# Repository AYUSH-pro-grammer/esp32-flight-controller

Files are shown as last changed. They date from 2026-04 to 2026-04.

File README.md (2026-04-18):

# ESP32 Flight Controller (Custom PCB)

## Description

This project presents a basic custom flight controller that is based on the ESP32 and MPU6050 IMU chip. The project reads data from the sensors, uses PID control to stabilize the drone, and drives four motors through electronic speed controllers (ESC).

## How PCB will look
PCB Image

## kicad schematic

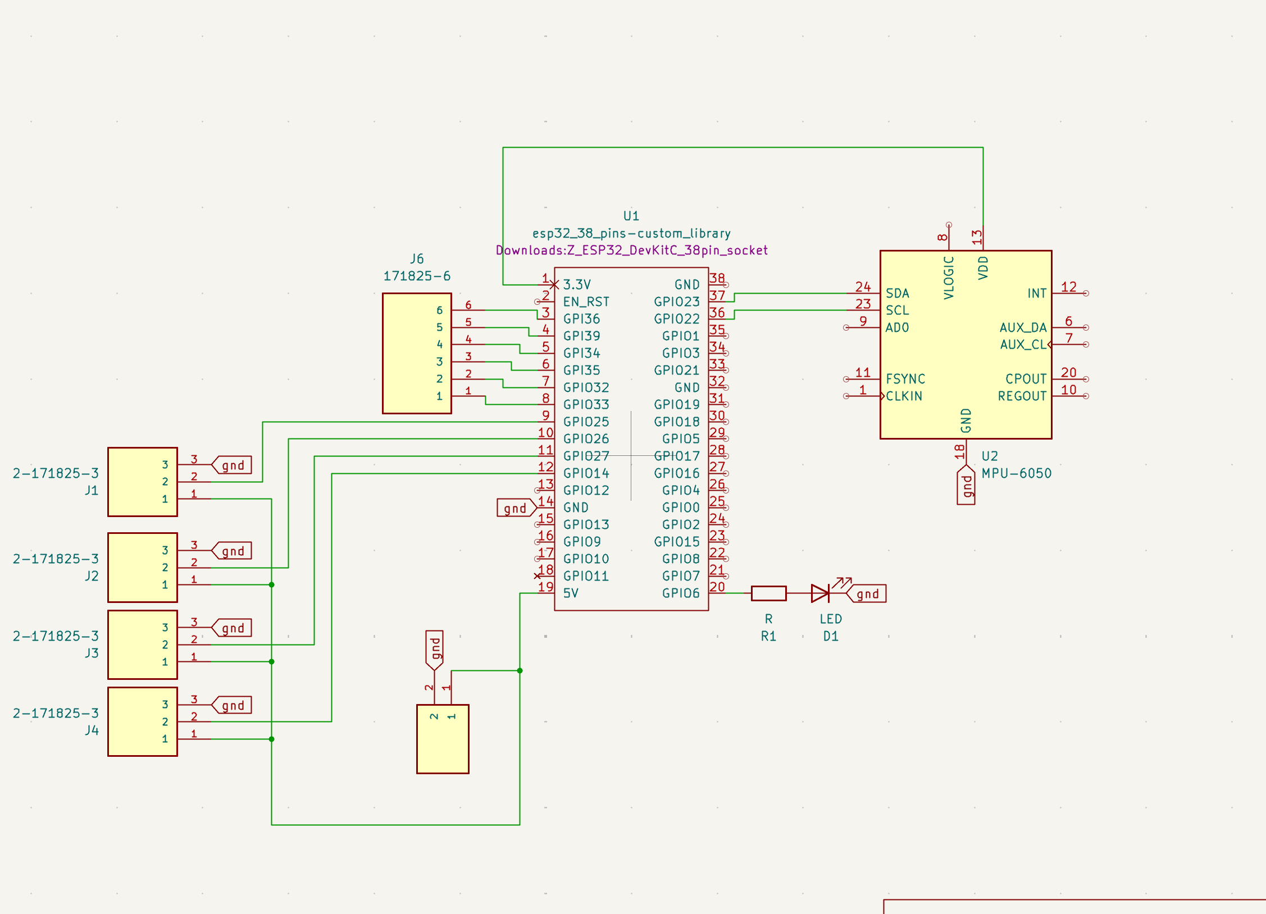
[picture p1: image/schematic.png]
Schematic


The repository contains:

* Code for the flight controller
* Code for IMU calibration
* Files with PCB design (KiCad)
* Gerber files for board manufacture

---

## Project Directory Structure

```
flight-controller-code/
├── flightController.ino   # Flight controller code
├── calibration.ino        # IMU calibration code
├── kicad/                 # PCB design files
├── image/                 # Board images
├── main_grb.zip           # Gerber files for fabrication
└── README.md
```

---

## Features

* Integration of MPU6050 accelerometer and gyroscope
* Complementary filter algorithm for angle calculations
* Double-loop PID control (angle and angle rate)
* PWM signals to control 4 ESC motors
* Input from the RC receiver (6 channels)
* IMU calibration for accurate sensor offset values

---

## Hardware Requirements

* ESP32 microcontroller
* MPU6050 IMU
* 4 electronic speed controllers with brushless motors
* RC receiver (PWM protocol)
* LiPo battery
* Custom PCB (designed in KiCad, files in `kicad/` folder)

---

## Setup Procedure

### Step 1 - Upload Calibration Code

1. Load file `calibration.ino`
2. Program ESP32 with this code
3. Put the drone on the ground
4. Open the Serial Monitor window
5. Read instruction messages and save the output values

---

### Step 2 - Fill IMU Offset Values

Fill the calibration values into the file `flightController.ino`:

```
float rateRollOffset = ...;
float ratePitchOffset = ...;
float rateYawOffset = ...;

float accXOffset = ...;
float accYOffset = ...;
float accZOffset = ...;
```

---

### Step 3 - Upload the Main Code

* Load `flightController.ino`
* Program ESP30 with this code

---

## Controls (RC Mapping)

| Channel | Function  |
| --- | --- |
| CH1 | Roll |
| CH2 | Pitch |
| CH3 | Throttle  |
| CH4 | Yaw |
| CH5/CH6 | Auxiliary |

---

## Important Tips

* Make sure your motors are installed correctly
* Do not run any tests with propellers mounted
* Fine-tune PID coefficients for better stability
* Calibrate your sensors carefully for optimal results

---

## Safety

* Do not power the motors with mounted propellers
* Ensure reliable power supply
* Have your hand near the throttle button

---

## Possible Upgrades

* Build-in fail-safe system
* Implement altitude hold function
* Enable GPS functionality
* Improve filtering algorithm (Kalman filter)

---

## Reference Code

Key code fragments are found in the following file:

---

## License

This project is open-source and can be freely modified.

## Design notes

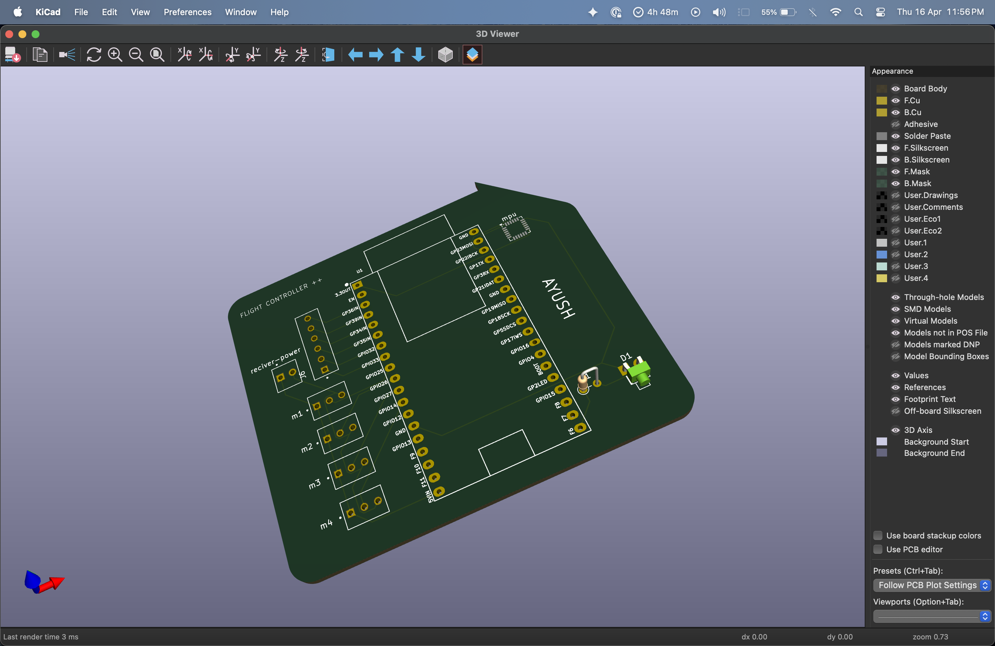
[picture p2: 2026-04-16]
image/3d.png

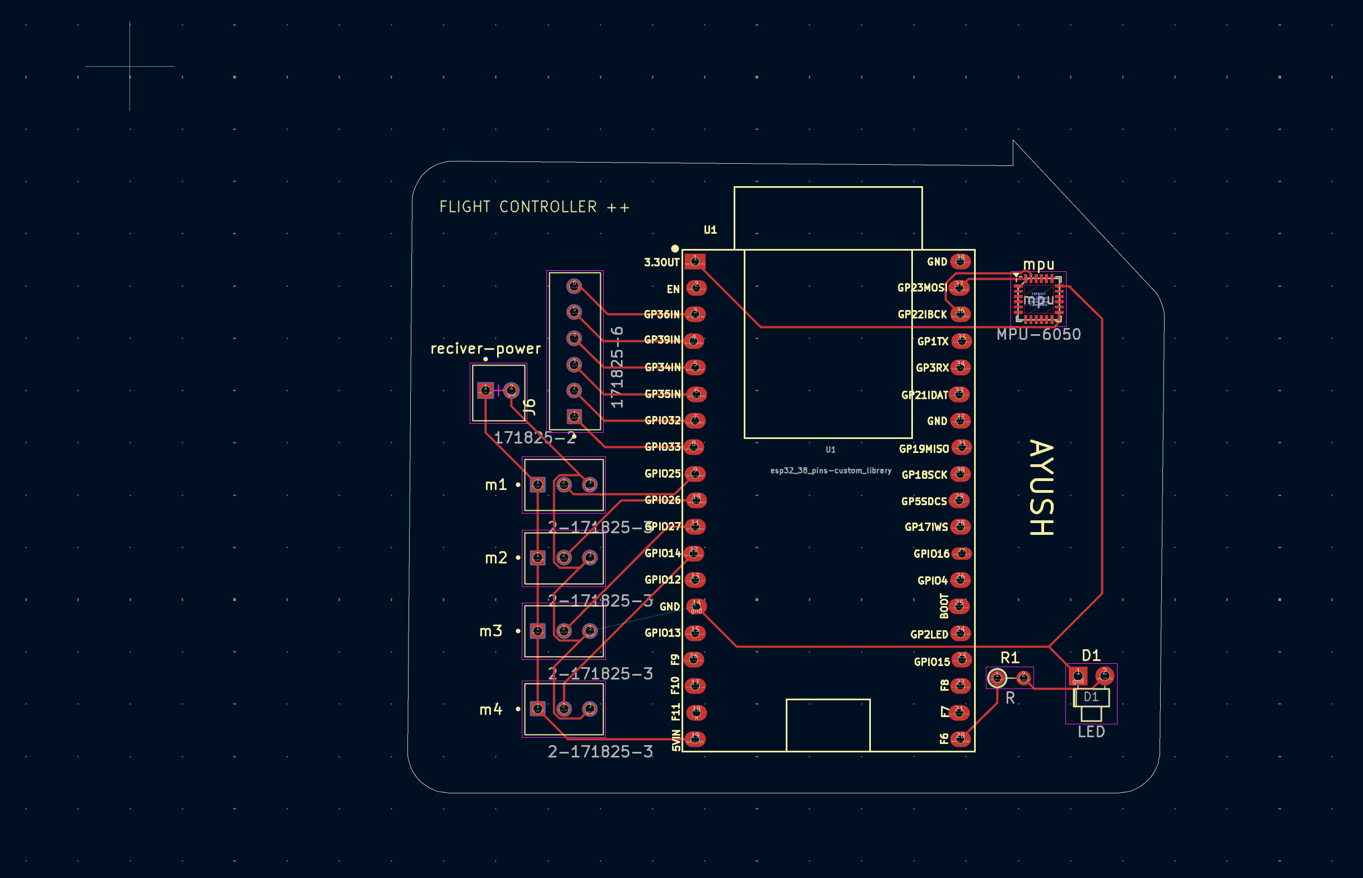
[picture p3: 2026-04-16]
image/pcb-editer.png

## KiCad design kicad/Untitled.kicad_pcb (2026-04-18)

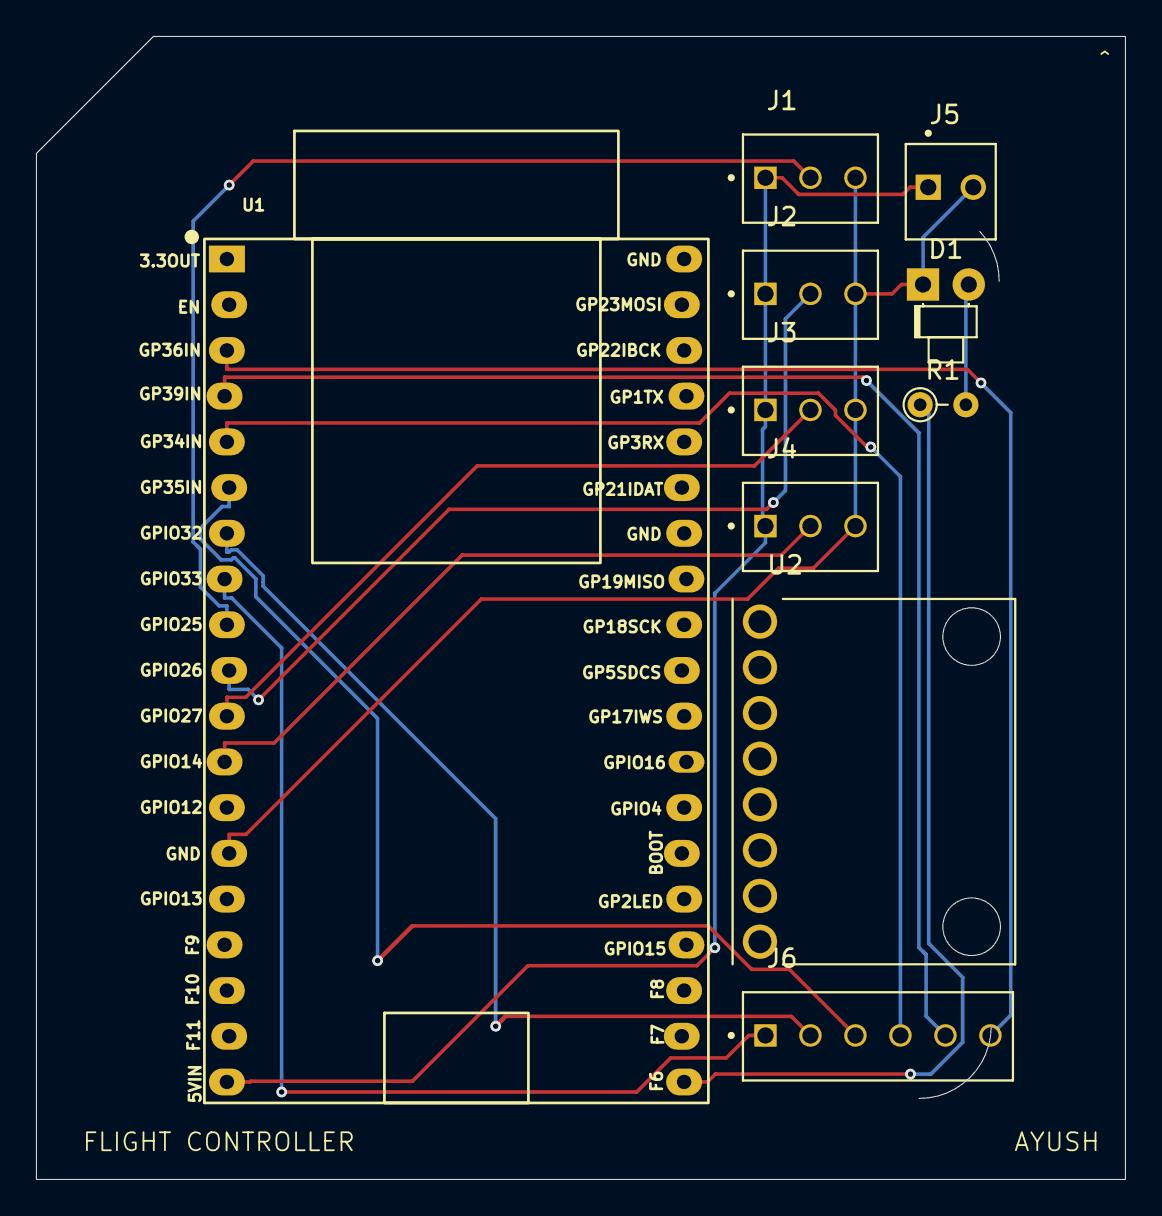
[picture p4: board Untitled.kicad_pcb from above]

Board: 2 copper layers, 60.5 x 63.5 mm, 10 parts (0 on the bottom side), 14 nets.

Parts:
D1: LED; LED_D1.8mm_W1.8mm_H2.4mm_Horizontal_O1.27mm_Z1.6mm
J1, J2, J3, J4: 2-171825-3; TE_2-171825-3
J5: 171825-2; TE_171825-2
J6: 171825-6; TE_171825-6
R1: R; R_Axial_DIN0204_L3.6mm_D1.6mm_P2.54mm_Vertical
U1: esp32_38_pins-custom_library; Z_ESP32_DevKitC_38pin_socket
U2: MPU-6050; MODULE_GY-521

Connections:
unnamed: D1.2 (A), R1.2
unnamed: J1.1, J2.1, J3.1, J4.1, J5.1, U1.19 (5V)
unnamed: J6.4, U1.5 (GPI34)
unnamed: J6.3, U1.6 (GPI35)
unnamed: J6.6, U1.3 (GPI36)
unnamed: J6.5, U1.4 (GPI39)
unnamed: R1.1, U1.20 (GPIO6)
unnamed: J4.2, U1.12 (GPIO14)
unnamed: J1.2, U1.9 (GPIO25)
unnamed: J2.2, U1.10 (GPIO26)
unnamed: J3.2, U1.11 (GPIO27)
unnamed: J6.2, U1.7 (GPIO32)
unnamed: J6.1, U1.8 (GPIO33)
gnd: D1.1 (K), J1.3, J2.3, J3.3, J4.3, J5.2, U1.14 (GND)

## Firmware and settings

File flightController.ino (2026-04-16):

#include <Wire.h>
#include <ESP32Servo.h>

const uint8_t MPU_ADDR = 0x68;
const float RAD_TO_DEG = 57.2957795f;
const float dt = 0.004f;

// IMU raw and converted values
int16_t accXRaw, accYRaw, accZRaw;
int16_t gyroXRaw, gyroYRaw, gyroZRaw;

float accX = 0.0f, accY = 0.0f, accZ = 0.0f;
float rateRoll = 0.0f, ratePitch = 0.0f, rateYaw = 0.0f;

// paste calibration values here
float rateRollOffset = 0.0f;
float ratePitchOffset = 0.0f;
float rateYawOffset = 0.0f;
float accXOffset = 0.0f;
float accYOffset = 0.0f;
float accZOffset = 0.0f;

float angleRoll = 0.0f;
float anglePitch = 0.0f;
float compAngleRoll = 0.0f;
float compAnglePitch = 0.0f;

// motors
Servo motor1, motor2, motor3, motor4;

const int motor1Pin = 13;
const int motor2Pin = 12;
const int motor3Pin = 14;
const int motor4Pin = 27;

const int escFrequency = 500;
const int throttleIdle = 1170;
const int throttleCutoff = 1000;

float motor1Out = 1000.0f;
float motor2Out = 1000.0f;
float motor3Out = 1000.0f;
float motor4Out = 1000.0f;

// receiver
volatile int receiverValue[6] = {1500, 1500, 1000, 1500, 1500, 1500};

const int ch1Pin = 34;
const int ch2Pin = 35;
const int ch3Pin = 32;
const int ch4Pin = 33;
const int ch5Pin = 25;
const int ch6Pin = 26;

volatile uint32_t currentTime = 0;
volatile uint32_t lastRise1 = 0, lastRise2 = 0, lastRise3 = 0, lastRise4 = 0, lastRise5 = 0, lastRise6 = 0;
volatile bool lastState1 = false, lastState2 = false, lastState3 = false, lastState4 = false, lastState5 = false, lastState6 = false;

// pid gains
float kpAngleRoll = 2.0f;
float kiAngleRoll = 0.5f;
float kdAngleRoll = 0.007f;

float kpAnglePitch = 2.0f;
float kiAnglePitch = 0.5f;
float kdAnglePitch = 0.007f;

float kpRateRoll = 0.625f;
float kiRateRoll = 2.1f;
float kdRateRoll = 0.0088f;

float kpRatePitch = 0.625f;
float kiRatePitch = 2.1f;
float kdRatePitch = 0.0088f;

float kpRateYaw = 4.0f;
float kiRateYaw = 3.0f;
float kdRateYaw = 0.0f;

// pid state
float desiredAngleRoll = 0.0f;
float desiredAnglePitch = 0.0f;
float desiredRateYaw = 0.0f;

float desiredRateRoll = 0.0f;
float desiredRatePitch = 0.0f;

float errorAngleRoll = 0.0f;
float errorAnglePitch = 0.0f;
float prevErrorAngleRoll = 0.0f;
float prevErrorAnglePitch = 0.0f;
float iTermAngleRoll = 0.0f;
float iTermAnglePitch = 0.0f;

float errorRateRoll = 0.0f;
float errorRatePitch = 0.0f;
float errorRateYaw = 0.0f;
float prevErrorRateRoll = 0.0f;
float prevErrorRatePitch = 0.0f;
float prevErrorRateYaw = 0.0f;
float iTermRateRoll = 0.0f;
float iTermRatePitch = 0.0f;
float iTermRateYaw = 0.0f;

float outRoll = 0.0f;
float outPitch = 0.0f;
float outYaw = 0.0f;

uint32_t loopTimer = 0;

float clampf(float value, float low, float high) {
  if (value < low) return low;
  if (value > high) return high;
  return value;
}

float pidStep(float error, float kp, float ki, float kd, float &integral, float &prevError) {
  integral += ki * error * dt;
  integral = clampf(integral, -400.0f, 400.0f);

  float derivative = kd * (error - prevError) / dt;
  float output = kp * error + integral + derivative;

  prevError = error;
  return clampf(output, -400.0f, 400.0f);
}

void setupMPU() {
  Wire.beginTransmission(MPU_ADDR);
  Wire.write(0x6B);
  Wire.write(0x00);
  Wire.endTransmission();

  Wire.beginTransmission(MPU_ADDR);
  Wire.write(0x1A);
  Wire.write(0x05);
  Wire.endTransmission();

  Wire.beginTransmission(MPU_ADDR);
  Wire.write(0x1C);
  Wire.write(0x10);
  Wire.endTransmission();

  Wire.beginTransmission(MPU_ADDR);
  Wire.write(0x1B);
  Wire.write(0x08);
  Wire.endTransmission();
}

void readMPU() {
  Wire.beginTransmission(MPU_ADDR);
  Wire.write(0x3B);
  Wire.endTransmission();

  if (Wire.requestFrom(MPU_ADDR, (uint8_t)6) != 6) return;

  accXRaw = (Wire.read() << 8) | Wire.read();
  accYRaw = (Wire.read() << 8) | Wire.read();
  accZRaw = (Wire.read() << 8) | Wire.read();

  Wire.beginTransmission(MPU_ADDR);
  Wire.write(0x43);
  Wire.endTransmission();

  if (Wire.requestFrom(MPU_ADDR, (uint8_t)6) != 6) return;

  gyroXRaw = (Wire.read() << 8) | Wire.read();
  gyroYRaw = (Wire.read() << 8) | Wire.read();
  gyroZRaw = (Wire.read() << 8) | Wire.read();

  accX = (float)accXRaw / 4096.0f;
  accY = (float)accYRaw / 4096.0f;
  accZ = (float)accZRaw / 4096.0f;

  rateRoll = (float)gyroXRaw / 65.5f;
  ratePitch = (float)gyroYRaw / 65.5f;
  rateYaw = (float)gyroZRaw / 65.5f;

  rateRoll -= rateRollOffset;
  ratePitch -= ratePitchOffset;
  rateYaw -= rateYawOffset;

  accX -= accXOffset;
  accY -= accYOffset;
  accZ -= accZOffset;

  angleRoll = atan2f(accY, sqrtf(accX * accX + accZ * accZ)) * RAD_TO_DEG;
  anglePitch = -atan2f(accX, sqrtf(accY * accY + accZ * accZ)) * RAD_TO_DEG;
}

void IRAM_ATTR readReceiver() {
  currentTime = micros();

  bool s1 = digitalRead(ch1Pin);
  if (s1 && !lastState1) {
    lastState1 = true;
    lastRise1 = currentTime;
  } else if (!s1 && lastState1) {
    lastState1 = false;
    receiverValue[0] = currentTime - lastRise1;
  }

  bool s2 = digitalRead(ch2Pin);
  if (s2 && !lastState2) {
    lastState2 = true;
    lastRise2 = currentTime;
  } else if (!s2 && lastState2) {
    lastState2 = false;
    receiverValue[1] = currentTime - lastRise2;
  }

  bool s3 = digitalRead(ch3Pin);
  if (s3 && !lastState3) {
    lastState3 = true;
    lastRise3 = currentTime;
  } else if (!s3 && lastState3) {
    lastState3 = false;
    receiverValue[2] = currentTime - lastRise3;
  }

  bool s4 = digitalRead(ch4Pin);
  if (s4 && !lastState4) {
    lastState4 = true;
    lastRise4 = currentTime;
  } else if (!s4 && lastState4) {
    lastState4 = false;
    receiverValue[3] = currentTime - lastRise4;
  }

  bool s5 = digitalRead(ch5Pin);
  if (s5 && !lastState5) {
    lastState5 = true;
    lastRise5 = currentTime;
  } else if (!s5 && lastState5) {
    lastState5 = false;
    receiverValue[4] = currentTime - lastRise5;
  }

  bool s6 = digitalRead(ch6Pin);
  if (s6 && !lastState6) {
    lastState6 = true;
    lastRise6 = currentTime;
  } else if (!s6 && lastState6) {
    lastState6 = false;
    receiverValue[5] = currentTime - lastRise6;
  }
}

void setup() {
  Serial.begin(115200);

  pinMode(ch1Pin, INPUT);
  pinMode(ch2Pin, INPUT);
  pinMode(ch3Pin, INPUT);
  pinMode(ch4Pin, INPUT);
  pinMode(ch5Pin, INPUT);
  pinMode(ch6Pin, INPUT);

  attachInterrupt(digitalPinToInterrupt(ch1Pin), readReceiver, CHANGE);
  attachInterrupt(digitalPinToInterrupt(ch2Pin), readReceiver, CHANGE);
  attachInterrupt(digitalPinToInterrupt(ch3Pin), readReceiver, CHANGE);
  attachInterrupt(digitalPinToInterrupt(ch4Pin), readReceiver, CHANGE);
  attachInterrupt(digitalPinToInterrupt(ch5Pin), readReceiver, CHANGE);
  attachInterrupt(digitalPinToInterrupt(ch6Pin), readReceiver, CHANGE);

  Wire.begin();
  Wire.setClock(400000);
  setupMPU();

  ESP32PWM::allocateTimer(0);
  ESP32PWM::allocateTimer(1);
  ESP32PWM::allocateTimer(2);
  ESP32PWM::allocateTimer(3);

  motor1.setPeriodHertz(escFrequency);
  motor2.setPeriodHertz(escFrequency);
  motor3.setPeriodHertz(escFrequency);
  motor4.setPeriodHertz(escFrequency);

  motor1.attach(motor1Pin, 1000, 2000);
  motor2.attach(motor2Pin, 1000, 2000);
  motor3.attach(motor3Pin, 1000, 2000);
  motor4.attach(motor4Pin, 1000, 2000);

  motor1.writeMicroseconds(throttleCutoff);
  motor2.writeMicroseconds(throttleCutoff);
  motor3.writeMicroseconds(throttleCutoff);
  motor4.writeMicroseconds(throttleCutoff);

  delay(2000);
  loopTimer = micros();
}

void loop() {
  readMPU();

  compAngleRoll = 0.98f * (compAngleRoll + rateRoll * dt) + 0.02f * angleRoll;
  compAnglePitch = 0.98f * (compAnglePitch + ratePitch * dt) + 0.02f * anglePitch;

  compAngleRoll = clampf(compAngleRoll, -20.0f, 20.0f);
  compAnglePitch = clampf(compAnglePitch, -20.0f, 20.0f);

  desiredAngleRoll = (receiverValue[0] - 1500) * 0.1f;
  desiredAnglePitch = (receiverValue[1] - 1500) * 0.1f;
  desiredRateYaw = (receiverValue[3] - 1500) * 0.15f;

  float throttle = (float)receiverValue[2];

  if (throttle < 1030.0f) {
    motor1Out = throttleCutoff;
    motor2Out = throttleCutoff;
    motor3Out = throttleCutoff;
    motor4Out = throttleCutoff;

    iTermAngleRoll = 0.0f;
    iTermAnglePitch = 0.0f;
    iTermRateRoll = 0.0f;
    iTermRatePitch = 0.0f;
    iTermRateYaw = 0.0f;

    prevErrorAngleRoll = 0.0f;
    prevErrorAnglePitch = 0.0f;
    prevErrorRateRoll = 0.0f;
    prevErrorRatePitch = 0.0f;
    prevErrorRateYaw = 0.0f;

    motor1.writeMicroseconds((int)motor1Out);
    motor2.writeMicroseconds((int)motor2Out);
    motor3.writeMicroseconds((int)motor3Out);
    motor4.writeMicroseconds((int)motor4Out);

    while (micros() - loopTimer < (uint32_t)(dt * 1000000.0f)) {}
    loopTimer = micros();
    return;
  }

  throttle = clampf(throttle, (float)throttleCutoff, 1800.0f);

  errorAngleRoll = desiredAngleRoll - compAngleRoll;
  errorAnglePitch = desiredAnglePitch - compAnglePitch;

  desiredRateRoll = pidStep(errorAngleRoll, kpAngleRoll, kiAngleRoll, kdAngleRoll, iTermAngleRoll, prevErrorAngleRoll);
  desiredRatePitch = pidStep(errorAnglePitch, kpAnglePitch, kiAnglePitch, kdAnglePitch, iTermAnglePitch, prevErrorAnglePitch);

  errorRateRoll = desiredRateRoll - rateRoll;
  errorRatePitch = desiredRatePitch - ratePitch;
  errorRateYaw = desiredRateYaw - rateYaw;

  outRoll = pidStep(errorRateRoll, kpRateRoll, kiRateRoll, kdRateRoll, iTermRateRoll, prevErrorRateRoll);
  outPitch = pidStep(errorRatePitch, kpRatePitch, kiRatePitch, kdRatePitch, iTermRatePitch, prevErrorRatePitch);
  outYaw = pidStep(errorRateYaw, kpRateYaw, kiRateYaw, kdRateYaw, iTermRateYaw, prevErrorRateYaw);

  motor1Out = throttle - outRoll - outPitch - outYaw;
  motor2Out = throttle - outRoll + outPitch + outYaw;
  motor3Out = throttle + outRoll + outPitch - outYaw;
  motor4Out = throttle + outRoll - outPitch + outYaw;

  motor1Out = clampf(motor1Out, throttleCutoff, 2000.0f);
  motor2Out = clampf(motor2Out, throttleCutoff, 2000.0f);
  motor3Out = clampf(motor3Out, throttleCutoff, 2000.0f);
  motor4Out = clampf(motor4Out, throttleCutoff, 2000.0f);

  if (motor1Out < throttleIdle) motor1Out = throttleIdle;
  if (motor2Out < throttleIdle) motor2Out = throttleIdle;
  if (motor3Out < throttleIdle) motor3Out = throttleIdle;
  if (motor4Out < throttleIdle) motor4Out = throttleIdle;

  motor1.writeMicroseconds((int)motor1Out);
  motor2.writeMicroseconds((int)motor2Out);
  motor3.writeMicroseconds((int)motor3Out);
  motor4.writeMicroseconds((int)motor4Out);

  while (micros() - loopTimer < (uint32_t)(dt * 1000000.0f)) {}
  loopTimer = micros();
}

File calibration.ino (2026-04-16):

// so in this fille we'll calibrate our drone and find values to be put in main file

#include <Wire.h>


int16_t AccXLSB, AccYLSB, AccZLSB;
int16_t gyrox, gyroy, gyroz;

float Accx, Accy, Accz;

volatile float RatePitch, RateRoll, RateYaw;
volatile float AccXCalibration, AccYCalibration, AccZCalibration;

volatile float RateCallPitch, RateCallRoll, RateCallTaw;
int RateCalibrationNumber;


void gyro_signals(){
    Wire.beginTransmission(0x68);
    Wire.write(0x1A);
    Wire.write(0x05);
    Wire.endTransmission();

    Wire.beginTransmission(0x68);
    Wire.write(0x1C);
    Wire.write(0x10);

    Wire.endTransmission(0x68);
    Wire.write(0x3B);
    Wire.endTransmission();



    Wire.requestForm(0x68, 6);
    GyroX = Wire.read() << 8 | Wire.read();
    GyroY = Wire.read() << 8 | Wire.read();
    GyroZ = Wire.read() << 8 | Wire.read();

    RateRoll = (float)GyroX / 65.5;
    RatePitch = (float)GyroY / 65.5;
    RateYaw = (float)GyroZ / 65.5;

    AccX = (float)AccXLSB / 4096;
    AccY = (float)AccYLSB / 4096;
    AccZ = (float)AccZLSB / 4096;



 }

void calibrateGyroSimple(){
    for (RateCalibrationNumber = 0; RateCalibrationNumber < 2000; RateCalibrationNumber++){
        gyro_signals();

        RateCallRoll += RateRoll;
        RateCallPitch += RatePitch;
        RateCallYaw += RateYaw;

        AccXCalibration += Accx;
        AccYCalibration += Accy;
        AccZCalibration += Accz;
        delay(1);
    }

    RateCallRoll /= 2000;
    RateCallPitch /= 2000;
    RateCallYaw /= 2000;


    AccXCalibration /= 2000;
    AccYCalibration /= 2000;
    AccZCalibration /= 2000;
    AccZCalibration = AccZCalibration - 1;
}


void setup(){
    Serial.begin(115200);
    Wire.begin():

    Wire.beginTransmission(0x68);
    Wire.write(0x6B);
    Wire.write(0x00);
    Wire.endTransmission(true);
    delay(1000);

    Serial.println("place the drone flat and press enter: ");

    while (!Serial.available()){

    }

    Serial.read();
    calibrateGyroSimple();

    Serial.println("Calibration done");


}

void loop(){


    gyro_signals();


    RateRoll -= RateCallRoll;
    RatePitch -= RateCallPitch;
    RateYaw -= RateCallYaw;

    Accx -= AccXCalibration;
    Accy -= AccYCalibration;
    Accz -= AccZCalibration;

    Serial.print("AccX: ");
    Serial.print(Accx);


    Serial.print("AccY: ");
    Serial.print(Accy);

    Serial.print("AccZ: ");
    Serial.print(AccZ);

    Serial.println("")

    Serial.print("Gyro X");
    Serial.print(RateRoll);

    Serial.print("Gyro Y");
    Serial.print(RatePitch);

    Serial.print("Gyro Z");
    Serial.print(RateYaw);

    delay(1);



}
